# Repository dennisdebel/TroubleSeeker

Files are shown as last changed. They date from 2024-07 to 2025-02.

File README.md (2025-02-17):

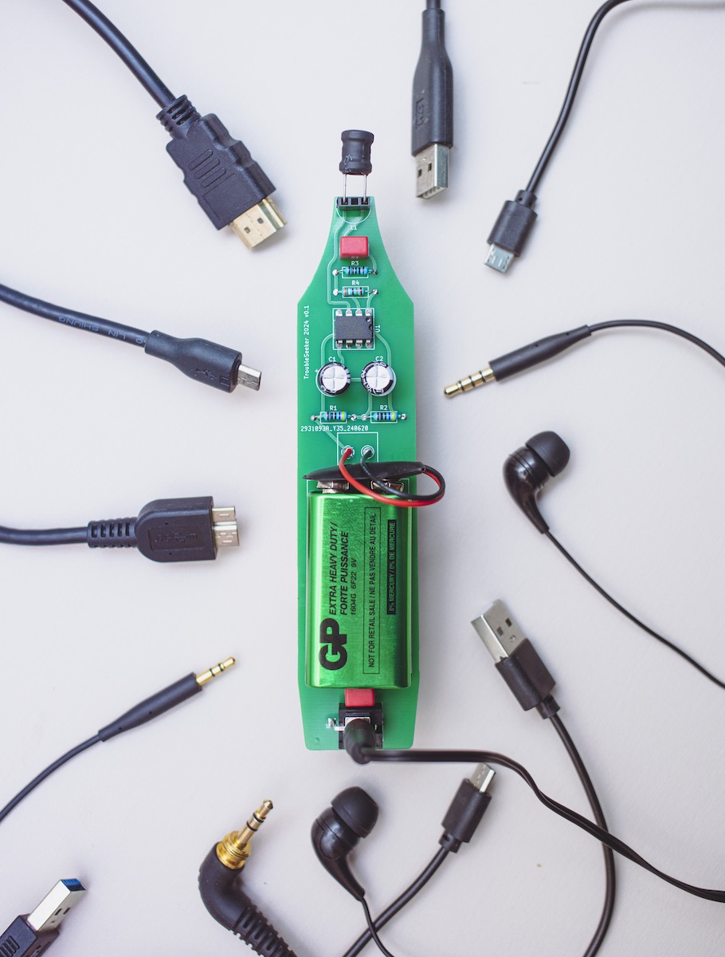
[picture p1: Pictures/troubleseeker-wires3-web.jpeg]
Assembled TroubleSeeker

# TroubleSeeker
Electromagnetic Radiation detector, based on the [Elektrosluch 3 by LOM Audio](https://store.lom.audio/products/elektrosluch-3?variant=4542168268832) re-designed for workshops (cost optimisation and ease of soldering). Perfboard variant can be found [here](https://makezine.com/projects/weekend-project-sample-weird-sounds-electromagnetic-fields)

Component values are non crucial.

Assembly tutorial [here](https://youtu.be/3JtvDqBiOzs)

First debuted at the TroubleMaker Shenzhen Reboot June 2024 Huaqiangbei.

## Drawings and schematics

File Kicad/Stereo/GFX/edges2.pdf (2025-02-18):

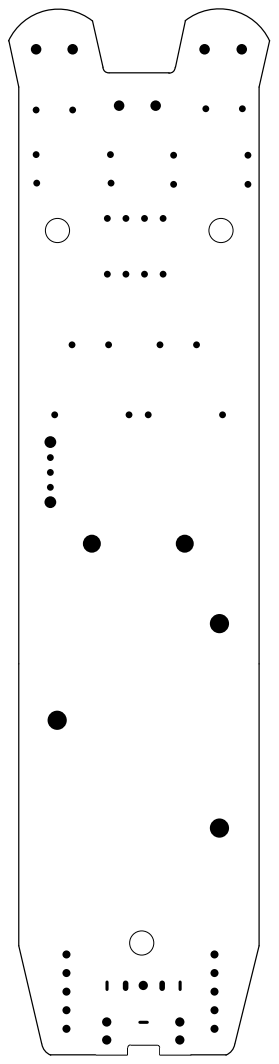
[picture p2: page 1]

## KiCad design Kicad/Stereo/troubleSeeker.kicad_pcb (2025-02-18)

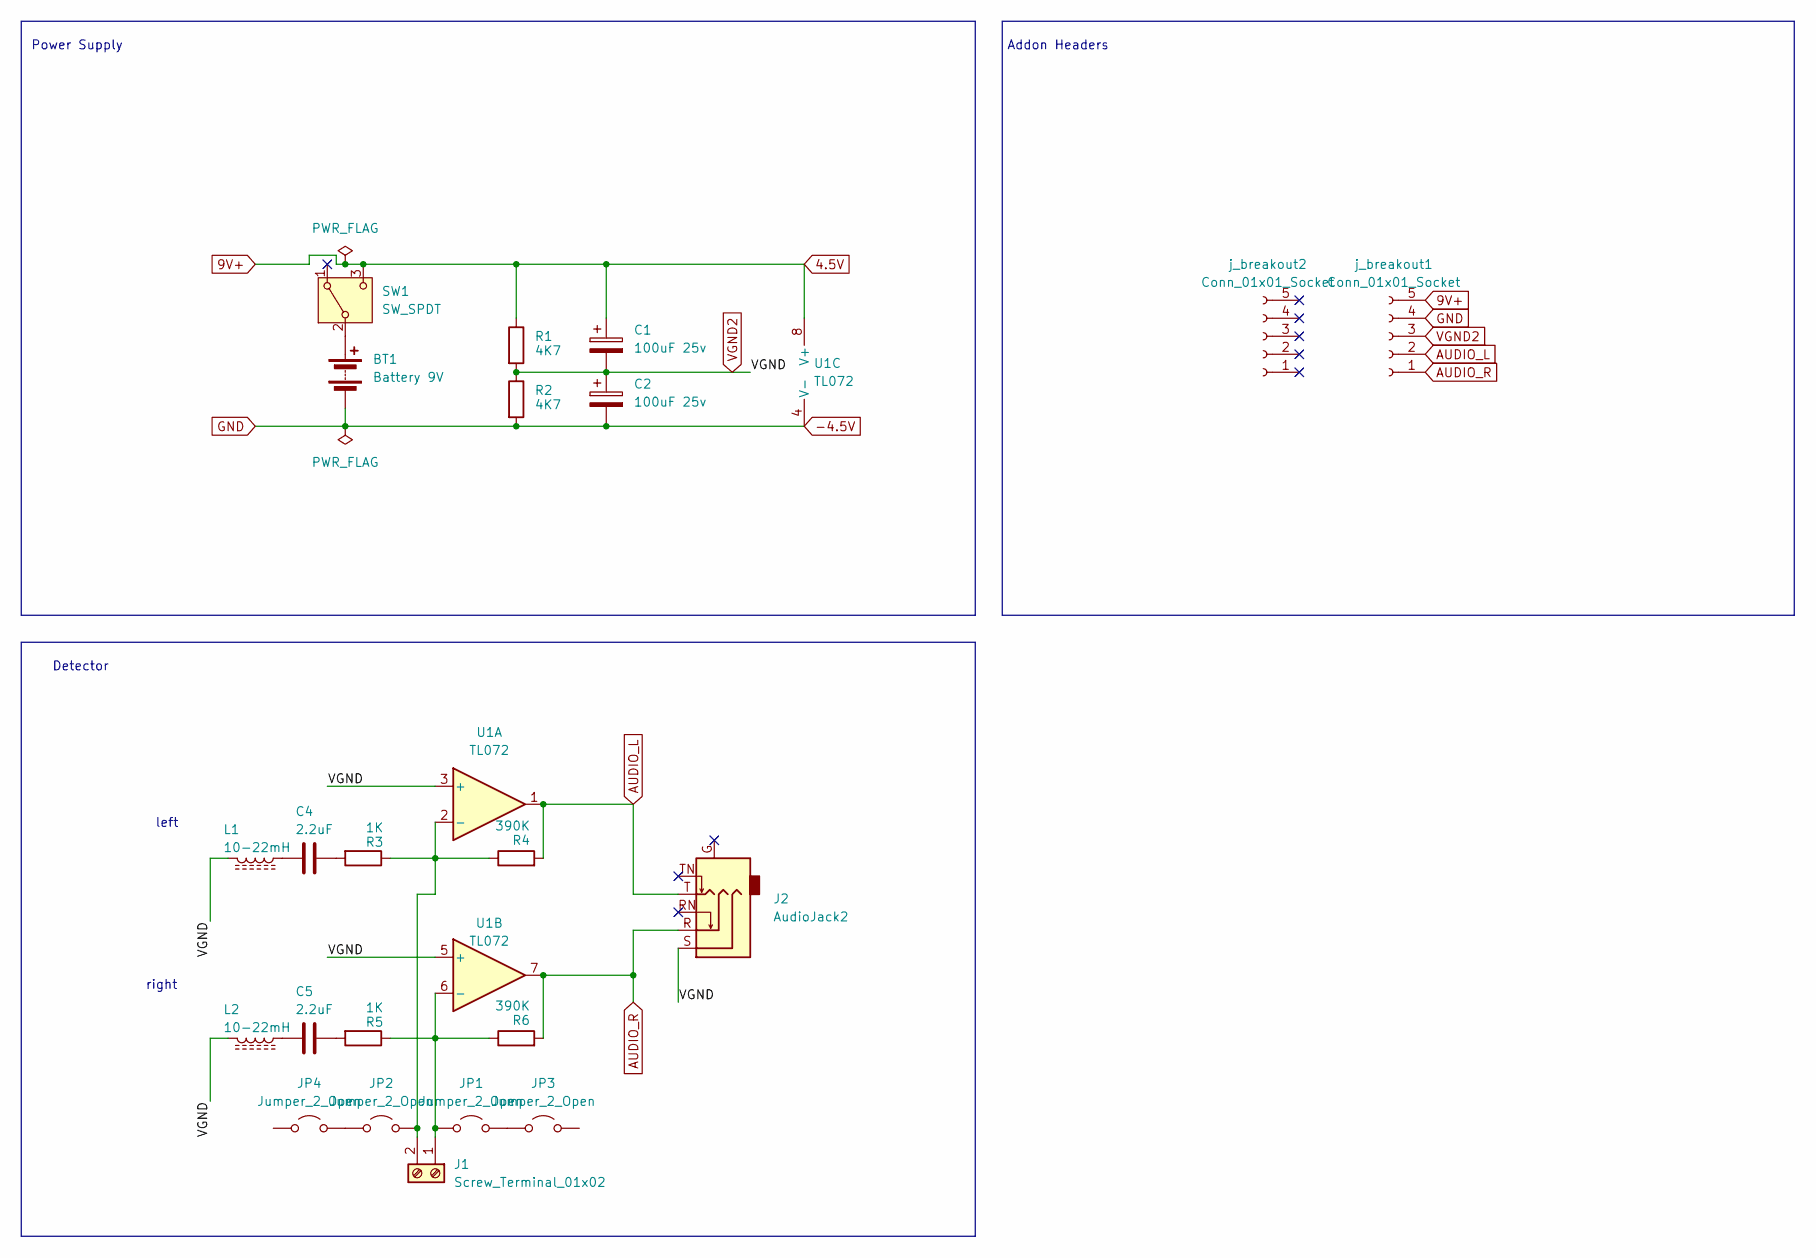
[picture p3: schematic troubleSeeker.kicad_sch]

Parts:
BT1: Battery 9V; BatteryHolder_Eagle_12BH611-GR
C1, C2: 100uF 25v; CP_Radial_D8.0mm_P5.00mm
C4, C5: 2.2uF; C_Rect_L7.2mm_W3.0mm_P5.00mm_FKS2_FKP2_MKS2_MKP2
J1: Screw_Terminal_01x02; TerminalBlock_MaiXu_MX126-5.0-02P_1x02_P5.00mm
J2: AudioJack2; Jack_3.5mm_CUI_SJ1-3525N_Horizontal
JP1, JP2, JP3, JP4: Jumper_2_Open; SolderJumper-2_P1.3mm_Open_RoundedPad1.0x1.5mm
L1, L2: 10-22mH; L_Radial_D8.7mm_P5.00mm_Fastron_07HCP
R1, R2: 4K7; R_Axial_DIN0207_L6.3mm_D2.5mm_P10.16mm_Horizontal
R3, R5: 1K; R_Axial_DIN0207_L6.3mm_D2.5mm_P10.16mm_Horizontal
R4, R6: 390K; R_Axial_DIN0207_L6.3mm_D2.5mm_P10.16mm_Horizontal
SW1: SW_SPDT; SW_Slide_SPDT_Angled_CK_OS102011MA1Q
U1: TL072; DIP-8_W7.62mm_Socket_LongPads
j_breakout1, j_breakout2: Conn_01x01_Socket; PinHeader_1x05_P2.54mm_Vertical

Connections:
4.5V: C1.1, R1.1, SW1.3 (C), U1.8 (V+), j_breakout1.5
-4.5V: BT1.2 (-), C2.2, R2.2, U1.4 (V-), j_breakout1.4
AUDIO_L: J2.T, R4.2, U1.1, j_breakout1.2
AUDIO_R: J2.R, R6.2, U1.7, j_breakout1.1
unnamed: BT1.1 (+), SW1.2 (B)
unnamed: C4.1, R3.2
unnamed: C4.2, L1.1
unnamed: C5.1, R5.2
unnamed: C5.2, L2.1
unnamed: J1.1, JP1.1 (A), R5.1, R6.1, U1.6 (-)
unnamed: J1.2, JP2.2 (B), R3.1, R4.1, U1.2 (-)
unnamed: JP1.2 (B), JP3.1 (A)
unnamed: JP2.1 (A), JP4.2 (B)
VGND2: C1.2, C2.1, J2.S, L1.2, L2.2, R1.2, R2.1, U1.3 (+), U1.5 (+), j_breakout1.3

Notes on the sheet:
Detector
Power Supply
Addon Headers
right
left

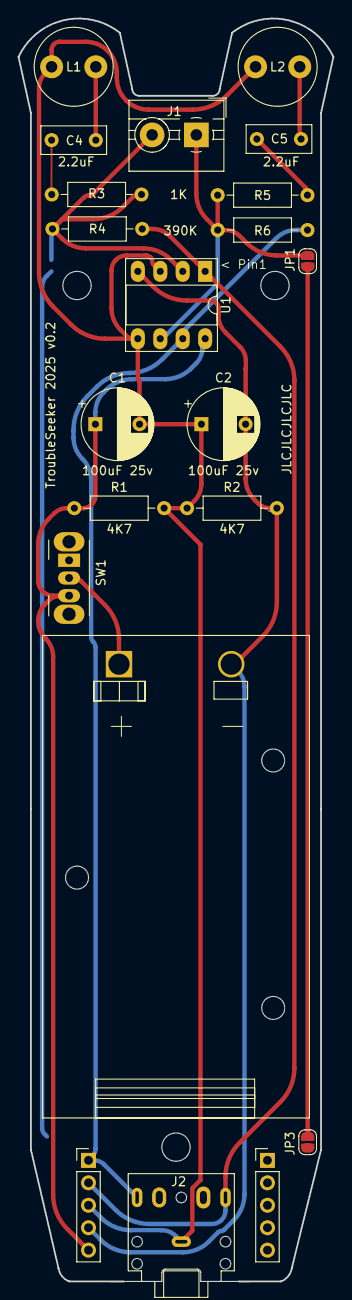
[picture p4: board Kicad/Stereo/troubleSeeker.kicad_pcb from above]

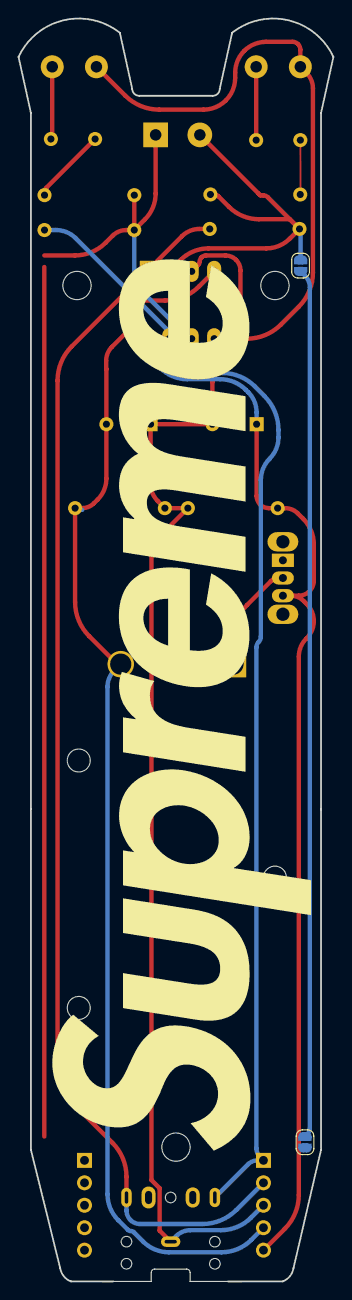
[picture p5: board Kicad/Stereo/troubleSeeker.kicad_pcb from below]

Board: 2 copper layers, 35.6 x 142.9 mm, 23 parts (3 on the bottom side), 14 nets.

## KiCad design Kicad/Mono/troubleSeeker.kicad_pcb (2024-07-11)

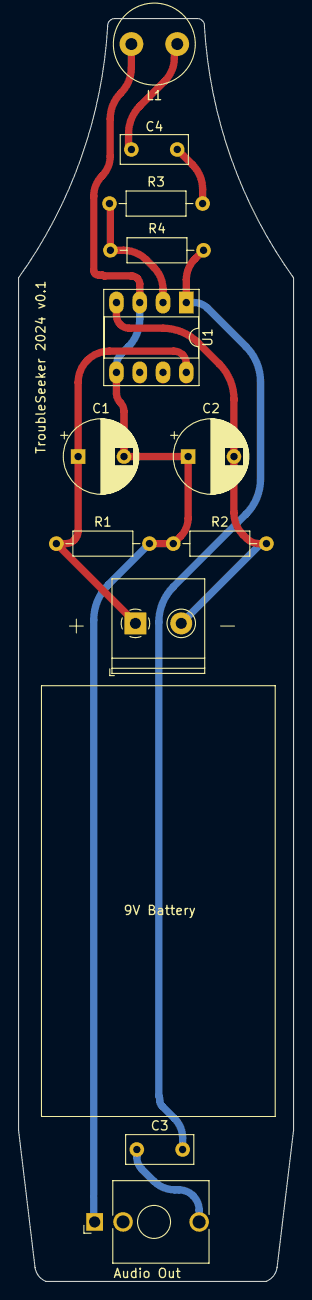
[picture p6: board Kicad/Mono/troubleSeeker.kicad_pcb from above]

Board: 2 copper layers, 30.0 x 137.8 mm, 12 parts (0 on the bottom side), 8 nets.

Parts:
9V Battery: Battery 9V; TerminalBlock_Philmore_TB132_1x02_P5.00mm_Horizontal
Audio Out: AudioJack2; Jack_3.5mm_QingPu_WQP-PJ398SM_Vertical_CircularHoles
C1, C2: 100uF 25v; CP_Radial_D8.0mm_P5.00mm
C3, C4: 2.2uF; C_Rect_L7.2mm_W3.0mm_P5.00mm_FKS2_FKP2_MKS2_MKP2
L1: 10-22mH; L_Radial_D8.7mm_P5.00mm_Fastron_07HCP
R1, R2: 4K7; R_Axial_DIN0207_L6.3mm_D2.5mm_P10.16mm_Horizontal
R3: 1K; R_Axial_DIN0207_L6.3mm_D2.5mm_P10.16mm_Horizontal
R4: 390K; R_Axial_DIN0207_L6.3mm_D2.5mm_P10.16mm_Horizontal
U1: TL072; DIP-8_W7.62mm_Socket_LongPads

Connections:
/VGND: Audio Out.S, C1.2, C2.1, L1.2, R1.2, R2.1, U1.3 (+), U1.5 (+)
unnamed: 9V Battery.1 (+), C1.1, R1.1, U1.8 (V+)
unnamed: 9V Battery.2 (-), C2.2, R2.2, U1.4 (V-)
unnamed: Audio Out.T, C3.1
unnamed: C3.2, R4.2, U1.1
unnamed: C4.1, R3.2
unnamed: C4.2, L1.1
unnamed: R3.1, R4.1, U1.2 (-)

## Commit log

2024-07-11 Added production files
    [troubleSeeker-B_Cu.gbr, troubleSeeker-B_Mask.gbr, troubleSeeker-B_Paste.gbr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]
2024-07-11 Added Kicad files
    [troubleSeeker.kicad_pcb, troubleSeeker.kicad_sch]
2025-02-17 Added Stereo Design
    [troubleSeeker.kicad_pcb, troubleSeeker.kicad_sch]
2025-02-17 Replaced switch
    [troubleSeeker.kicad_pcb, troubleSeeker.kicad_sch]
2025-02-18 added gerbers
    [troubleSeeker-B_Cu.gbr, troubleSeeker-B_Mask.gbr, troubleSeeker-B_Paste.gbr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]
2025-02-18 minor adjustments
    [troubleSeeker.kicad_pcb]
